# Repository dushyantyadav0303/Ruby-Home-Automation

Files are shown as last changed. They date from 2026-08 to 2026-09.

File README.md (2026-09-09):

<h1 align="center">
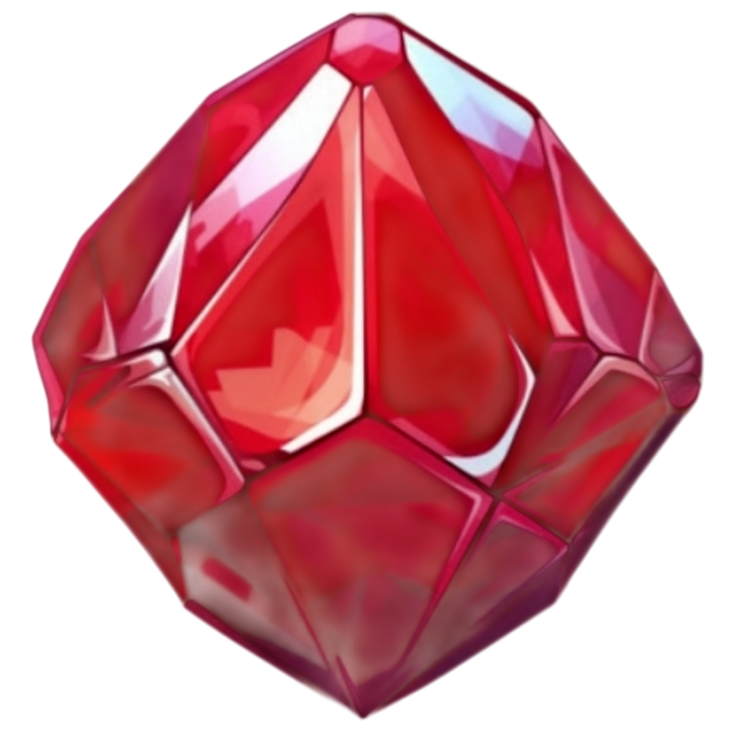
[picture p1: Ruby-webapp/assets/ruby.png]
banner
<br> 
</h1>
<div align="center">   
  

</div>

 <div align="center">   
  




</div>

<p align="center">
  <a href="#about-the-project">About</a> •
  <a href="#repository-structure">Structure</a> •
  <a href="#schematic">Schematic</a> •
  <a href="#pcb">PCB</a> •
  <a href="#cad">CAD</a> •
  <a href="#Render">Render</a> •
  <a href="#bill-of-materials">BOM</a> •
  <a href="#license">License</a> •
  <a href="#credits">Credits</a>
</p>  

https://github.com/user-attachments/assets/42d68add-5cff-4576-99cb-57eee04979b4

## Webapp: https://ruby-home-automation.vercel.app

### About the Project

**Ruby-Home-Automation** It is a aesthetic Home Automation Device With Multi color silkscreen, It connect with home Appliances and Make it control them using your phone From any corner of the world. And Also connect with Home assistant like Alexa & Google Assistant And control them using Voice command.
### Features

- **Wifi + ble**
- **Easy to configure with any firmware**
- **Controls 4 Lights, 1 fan With the 4 step Speed control, All the home appliances which uses IR Remote.**
- **IR receiver/IR Blaster**
- **Multicolor silkscreen**

## Repository Structure

- `src/PCB/` — EasyEDA project sources
- `src/cad/` — mechanical CAD sources
- `production/pcb/` — PCB fabrication files (Gerbers, BOM, Pick & Place)
- `production/cad/` — 3D-printing files (.stl + .3mf)
- `GETTING_STARTED/` — Setup guides, firmware installation, and board bring-up documentation
- `Journal/` — DevLogs With Timestamp
- `Firmware/` — Demo firmware

## Schematic

Source : `src/PCB/Sch`
## [Oshwlab](https://oshwlab.com/dushyant0303/project_avsrxfsp)
Schematic

## PCB 
Source : `src/PCB/Pcb`
~ 
<div align="center">

| Front PCB | Back PCB |
|---|---|
|  |  |
|  |  |

</div>

## CAD


A Encloser Case for Ruby home automation. The top part and bottom part are Friction fit , allowing the enclosure to be assembled without screws or Glue makes it easy assembly. And looks good.

- source: `src/cad/`
<div align="center">
<table>
<tr>
<td valign="bottom">
</td>
<td valign="bottom">
</table>
</div>
]

### 3D-printable Production files are available in:
- source: `production/cad/`

## Render 


<div align="center">
<table>
<tr>
<td valign="bottom">
</td>
<td valign="bottom">
</table>
</div>

## BOM

## Bill of Materials

Source: `BOM/BOM.csv`

|Quantity|Comment |Designator |Footprint |Price in USD|link |
|---|---|---|---|---|---|
|4 |0.1uf |C8,C1,C5,C7 |C0805 |$0.44 |https://www.lcsc.com/product-detail/C1711.html |
|1 |10nF |C2 |C0805 |$1.04 |https://www.lcsc.com/product-detail/C1710.html |
|1 |CH340C |U10 |SOP-16_L10.0-W3.9-P1.27-LS6.0-BL |$ 0.59 |https://www.lcsc.com/product-detail/C84681.html |
|1 |DHT11 |H1 |HDR-TH_4P-P2.54-V-M_146458-4 |$0.8 |https://robu.in/product/dht-11-digital-temperature-and-humidity-sensor-normal-quality |
|1 |ESP32-WROOM-32D |U12 |WIFIM-SMD_ESP32-WROOM-32D |$ 3.92 |https://www.lcsc.com/product-detail/C473012.html |
|1 |HT7833 |U11 |SOT-89_L4.5-W2.5-P1.50-LS4.2-BR |$ 0.61 |https://www.lcsc.com/product-detail/C3011187.html |
|1 |MX128-5.0-06P-GN01-Cu-Y-A|U13 |CONN-TH_6P-P5.00_MX128-5.0-06P-GN01-CU-Y-A|$ 0.36 |https://www.lcsc.com/product-detail/C5290371.html |
|1 |S6B-XH-A-GU |CN1 |CONN-TH_S6B-XH-A |$ 1.04 |https://www.lcsc.com/product-detail/C495565.html |
|1 |TSOP1738_TSOP1738 |U9 |TSOP1738:TSOP17XX |$ 0.43 |https://robocraze.com/products/tsop-1738 |
|1 |TYPE-C-31-M-12 |USBC1 |USB-C_SMD-TYPE-C-31-M-12_1 |$ 0.86 |https://www.lcsc.com/product-detail/C165948.html |
|1 |ULN2003LVDR |U1 |SOIC-16_L9.9-W3.9-P1.27-LS6.0-BL |$ 0.88 |https://www.lcsc.com/product-detail/C19723745.html |
|2 |2.2Ω |R22,R23 |RES-TH_BD2.2-L6.5-P10.50-D0.6 |$0.01 |https://kitsguru.com/products/2-2ω-resistance-1-4-watt-5-tolerance |
|2 |220kΩ |R14,R15 |RES-TH_BD4.5-L11.0-P15.00-D0.7 |$ 0.02 |https://robu.in/product/mf25-220k-multicomp-pro-through-hole-resistor-220-kohm-mf25-series-250-mw-±-1-axial-leaded-250-v/|
|2 |BC846B |Q5,Q6 |SOT-23-3_L2.9-W1.3-P1.90-LS2.4-BR |$ 0.76 |https://www.lcsc.com/product-detail/C181138.html |
|1 |2.2uf |C10 |CAP-TH_L12.0-W5.5-P10.00-D1.2 |$ 0.44 |https://www.lcsc.com/product-detail/Polypropylene-Film-Capacitors--CBB-_KNSCHA-MPP334J2G10AJ22610_C506821.html |
|1 |3.3uf |C9 |CAP-TH_L11.5-W6.3-P10.00-D0.6 |$ 0.44 |https://www.lcsc.com/product-detail/C22466724.html? |
|2 |TSA010A2518A |SW1,SW2 |SW-SMD_L4.0-W3.0-LS5.0 |$ 0.59 |https://www.lcsc.com/product-detail/C2888945.html |
|3 |5.1k |R8,R9,R19 |R0805_NEW |$ 1.13 |https://www.lcsc.com/product-detail/C27834.html |
|3 |10uF |C3,C4,C6 |C0805 |$ 0.52 |https://www.lcsc.com/product-detail/C27834.html |
|4 |10K |R7,R13,R20,R21 |R0805_NEW |$ 0.36 |https://www.lcsc.com/product-detail/C2907219.html |
|4 |LED |LED2,LED3,LED4,LED6 |LED0805-RD_RED_C0805YGC |$ 0.94 |https://www.lcsc.com/product-detail/C264434.html |
|6 |330Ω |R5,R6,R10,R11,R12,R25 |R0805_NEW |$ 0.56 |https://www.lcsc.com/product-detail/C19701189.html |
|7 |1k |R1,R2,R3,R4,R16,R17,R18 |R0805_NEW |$ 1.2 |https://www.lcsc.com/product-detail/C19699631.html |
|7 |1N4007W |D1,D2,D3,D4,D5,D6,D7 |SOD-123_L2.8-W1.8-LS3.7-RD |$ 0.72 |https://www.lcsc.com/product-detail/C2857183.html |
|7 |2N3904(SOT-23) |Q1,Q2,Q3,Q4,Q7,Q8,Q9 |SOT-23-3_L2.9-W1.3-P1.90-LS2.4-TR |$ 0.47 |https://www.lcsc.com/product-detail/C50176433.html |
|7 |IR333-A |U2,U3,U4,U5,U6,U7,U8 |LED-TH_BD6.2-P2.54-FD |$ 0.68 |https://www.lcsc.com/product-detail/C50176433.html |
|7 |SRD-05VDC-SL-C |RLY1,RLY2,RLY3,RLY4,RLY5,RLY6,RLY7|RELAY-TH_SRD-XXVDC-XL-C |$ 0.44 |https://www.lcsc.com/product-detail/C35449.html |
|1 |PCB | | |$14 |https://jlcpcb.com |
|Total | | | |$34.25 | |

> [!NOTE]
> Price As of August 25, 2026  <br/>
> & It not Include the Shipping fee

## License

Licensed under MIT — you can use this commercially, modify, and distribute 
with proper attribution. See [LICENSE](LICENSE) file.

## Contributing

Contributions, improvements, and remixes are welcome! Please read the [CONTRIBUTING.md](CONTRIBUTING.md) guide to get started.

## Credits
<div align="center">
  



 
</div>

This project was created during a [Hack Club](https://hackclub.com) event [Live YSWS](https://Live.hackclub.com).
- **[EasyEDA](https://easyeda.com)** - PCB design and schematic capture
- **[Fusion 360](https://www.autodesk.com/products/fusion-360)** - Cad Designing
- **[Blender](https://www.blender.org)** - Render
- **[@NotARoomba](https://github.com/notaroomba) & [@Gabouin](https://github.com/Gabouin)** - Readme template

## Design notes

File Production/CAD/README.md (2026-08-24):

# TOP

> [!IMPORTANT]
> This Should Be Printed in Transparent material like Clear Resin using SLA 3dp Technology.


----

| bottom | Led aliner |
| :---: | :---: |
|  |  |

| Specification | Default Value / Range |
| :--- | :--- |
| **Printer Nozzle** | 0.4 mm Stainless Steel | 
| **Layer Height** | 0.2 mm |
| **First Layer Height** | 0.2 mm |
| **Seam Position** | Random |
| **Nozzle Temperature** | Depends on your Filament |
| **Build Plate Temperature** | Depends on your Filament |
| **Sparse Infill Density** | 10% |
| **Max Toolhead Speed** | 500 mm/s |
| **Max Acceleration** | 10000 mm/s² |
| **Brim Width** | 3.5 mm |
| **Brim type** | Outer brim |

> [!NOTE] 
> Tested in Pla+ (Recommended)

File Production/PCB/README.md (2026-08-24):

| Ordering Detail | Cart |
| :---: | :---: |
| ordering-detail | cart |

~ Source [JLCPCB Docs](https://jlcpcb.com/help/article/how-to-design-multi-color-silkscreen-using-easyeda)
<details>
  <summary> Click to see "How to Design Multi-Color Silkscreen Using EasyEDA"</summary>

## Table of Contents
1. [Introduction](#introduction)
2. [Enabling Color Silkscreen Printing](#enabling-color-silkscreen-printing)
3. [Importing Color Images](#importing-color-images)
4. [Setting Component Silkscreen Colors](#setting-component-silkscreen-colors)
5. [Setting Board Silkscreen Colors](#setting-board-silkscreen-colors)
6. [Previewing Color Silkscreen](#previewing-color-silkscreen)
7. [Exporting Manufacturing Files](#exporting-manufacturing-files)
8. [Ordering Multi-Color Circuit Board](#ordering-multi-color-circuit-board)
9. [Important Notes for Multi-Color Silkscreen PCBs](#important-notes-for-multi-color-silkscreen-pcbs)

---

## Introduction

JLCPCB is one of the few PCB manufacturers capable of offering multi-color silkscreen services. To produce a multi-color circuit board, a design incorporating multi-color silkscreens is essential. At present, our production process exclusively supports Gerber files featuring colored silkscreen layers that have been exported from **EasyEDA Pro**. 

In the following guide, we will walk you through the process of designing multi-color silkscreens using EasyEDA Pro, including importing color images, setting character colors, and exporting manufacturing files for orders through JLCPCB.

---

## Enabling Color Silkscreen Printing

To begin, activate the "Use JLCPCB Color Silkscreen Process" option in the PCB settings:
* **Path:** Settings icon – PCB / Footprint – General – Using JLC color silkscreen technology

---

## Importing Color Images

1. EasyEDA supports importing color images via the **Top Menu – Place – Image**. 
2. Both **PNG** and **SVG** vector image files are supported. 
3. In the import dialog, tick the option to place the image in original quality. If this option is not available, try uploading the image in another file format.
4. The image will automatically be placed on the top silkscreen layer, but you can move it to the document layer or the bottom silkscreen layer if needed.

---

## Setting Component Silkscreen Colors

* After selecting a component, you can set its silkscreen color in the **right-side properties panel**.
* All lines, text, reference designators, and other silkscreen features belonging to the component will be printed in this color.

---

## Setting Board Silkscreen Colors

Click on a blank space on the canvas to access the color silkscreen settings in the right-side properties panel:
* **Top/Side Board Colors:** Default is white. Since the board requires color printing, a base color layer must be printed first, and this setting determines that base color.
* **Top/Bottom Side Silkscreen Colors:** The default silkscreen colors, like reference designators and component outline silkscreens. If a component has an individually set silkscreen color, it will take precedence over this default.

---

## Previewing Color Silkscreen

1. Go to **Top Menu – View – 2D/3D Preview**.
2. You must set **Silkscreen Technology** to **Colorful Silkscreen** in the right-side properties panel to see the effect of color printing.

---

## Exporting Manufacturing Files

1. After completing the settings and editing the color silkscreen, export the color silkscreen production file. 
2. Open **Top Menu – Export – PCB Fabrication File (Gerber)**.
3. Tick the **Silkscreen** option to export color silkscreen along with the Gerber files.

### Important SMT / Panelization Notes:
* **Edge Rails Requirement:** If your color silkscreen board requires JLCPCB SMT service, ensure that the "Panelize" function has been set with edge rails. Otherwise, the color silkscreen will not be printed when you select SMT service.
* Click "Set Technology Side", or access the Panelize menu from **Top Menu – Tools – Panelize**. Choose the panelization method ("Stamp Hole" / "V-CUT"), then enable process edges ("Create Technology Side"). The panel format can be 1×1 or larger.
* **EasyEDA Pro Version Support:** In EasyEDA Pro version 2.2 and above, color silkscreen panelization is supported when selecting **"All Objects"** as the panelization method within the Panelize tool. Currently, the "Board Outline Only" panelization method does not support color silkscreen.
* **Single-Layer Boards Caution:** Please exercise caution when designing single-layer boards with color silkscreen. If your single-layer routing is placed on the bottom layer, JLCPCB will mirror the bottom layer data to the top layer during manufacturing to optimize production efficiency and reduce costs. However, the color silkscreen data will not be mirrored synchronously, resulting in the color silkscreen being mistakenly printed over top layer pads. **Recommendation:** Place all routing on the top layer when designing single-layer boards, or design the project as a double-layer board by applying a copper pour to the unrouted layer.

---

## Ordering Multi-Color Circuit Board

You can place an order directly at EasyEDA, or upload Gerber files generated from EasyEDA on the JLCPCB quote page, where you need to select multi-color silkscreen specifications.

### Multi-Color Silkscreen PCB Specifications:

| Specification | Supported Option |
| :--- | :--- |
| **Layers** | 2 layers, 4 layers |
| **PCB Color** | White |
| **Outer Copper Weight** | 1oz |
| **Surface Finish** | ENIG |
| **Gold Thickness** | 1u |
| **Via Covering** | Tented, Untented, Plugged |
| **Delivery Format** | Single PCB, Panel by Customer |

* In the **"Advanced Options"**, select **"EasyEDA multi-color silkscreen"** under Silkscreen Technology.

---

## Important Notes for Multi-Color Silkscreen PCBs

1. **Gerber Adjustments Error Tolerance:** EasyEDA color silkscreen production files are separate from Gerber. JLCPCB adjusts customer's Gerber files to ensure compatibility with process conditions, but these adjustments do not carry over to color silkscreen files. If Gerber adjustments exceed the set error tolerance of **2 mm**, your color silkscreen will not be included in the production files.
2. **Panel Size for V-Cut:** Please ensure that the PCB panel size is **≥ 70×70 mm** if there is a V-Cut. For sizes smaller than this, please panel with mouse bites.
3. **Edge Rails for SMT Assembly:** When the size is less than 70×70 mm, the system will automatically add edge rails to enlarge the size, and engineers will align the multi-color silkscreen on the board. Edge rails are added with V-Cut for regular shapes and mouse bites for irregular shapes.
4. **EasyEDA Pro Panelize Limitation:** Currently, multi-color silkscreen is not fully supported by EasyEDA Pro's automatic Panelize feature, as automatic panelization does not duplicate multi-color silkscreen content. The exported multi-color silkscreen Gerber will only have data on the master board, and other boards will not contain multi-color silkscreen files.

</details>

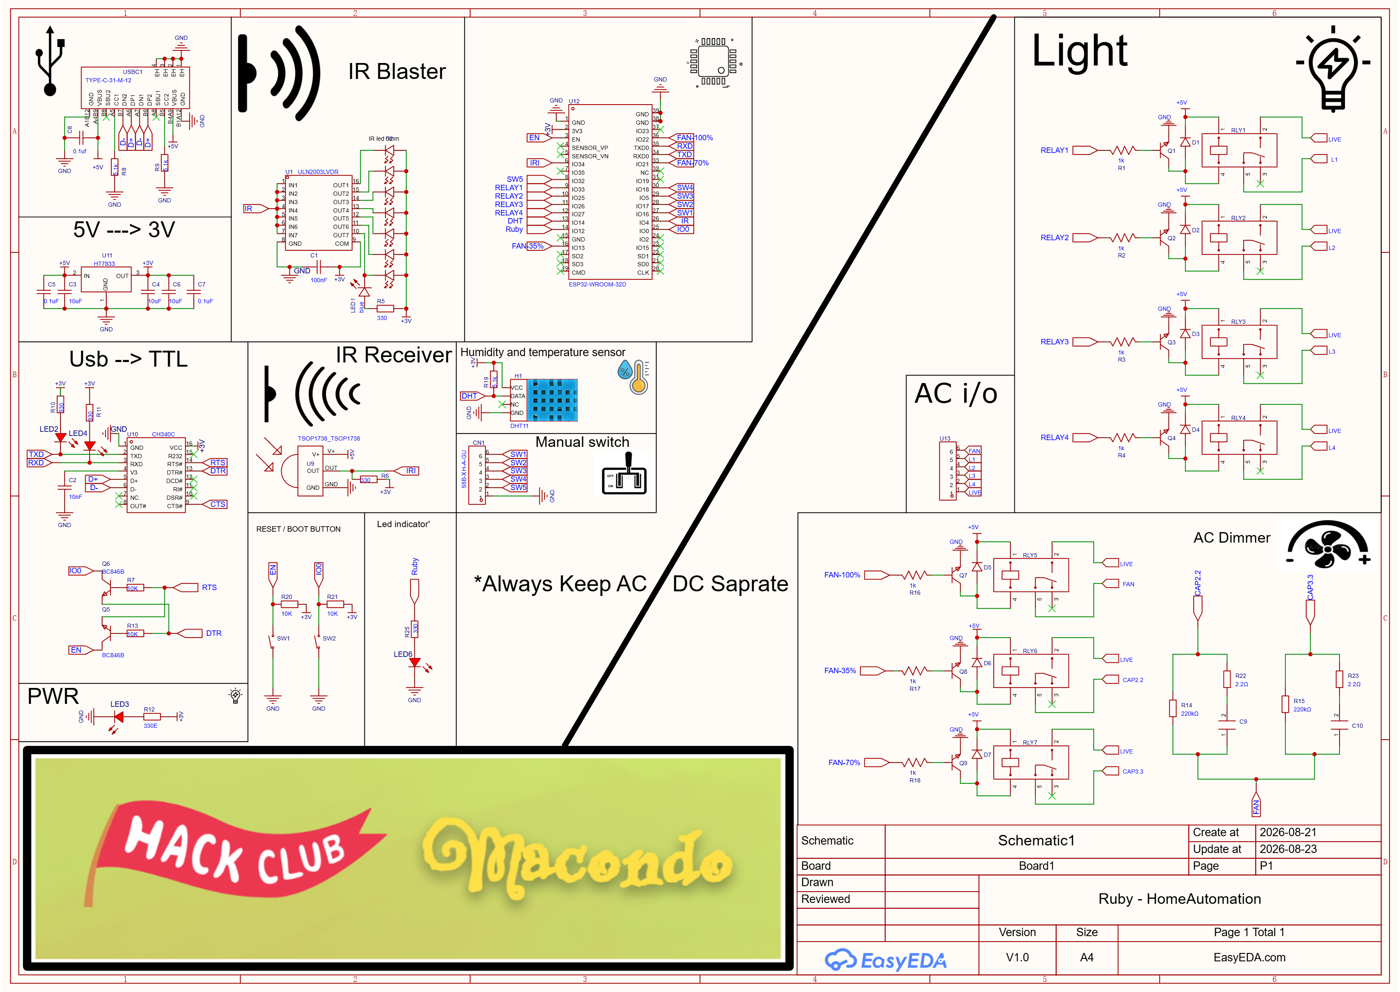
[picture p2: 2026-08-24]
src/PCB/Schematic.png

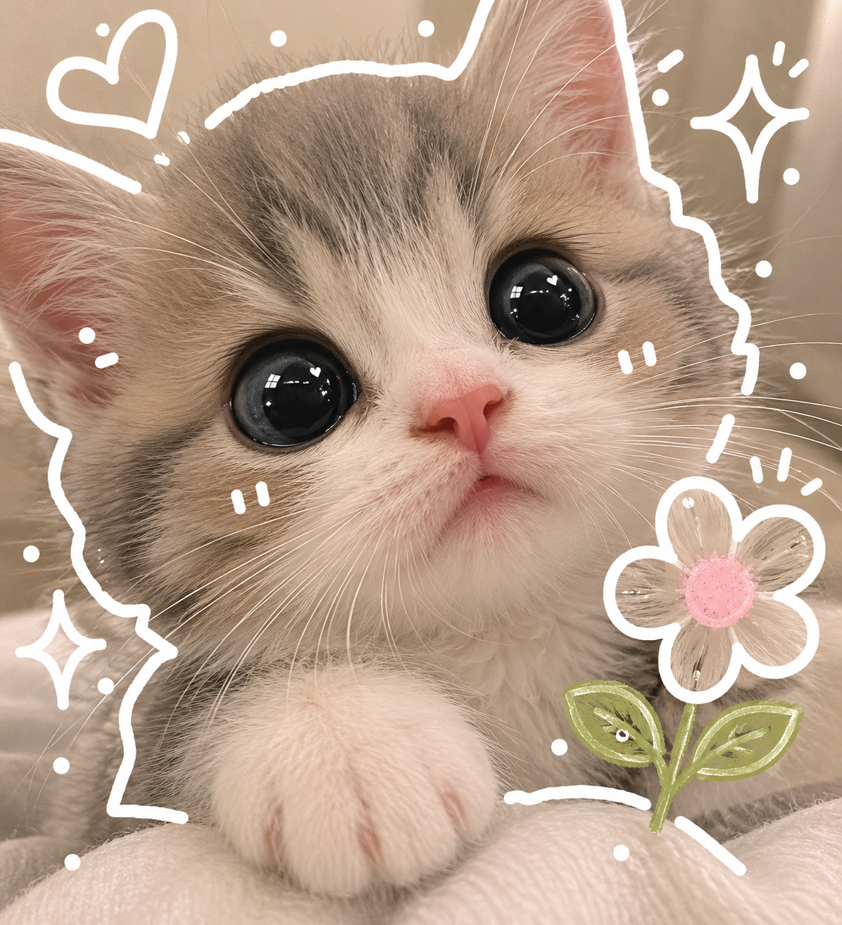
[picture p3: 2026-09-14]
Ruby-webapp/assets/photo.png

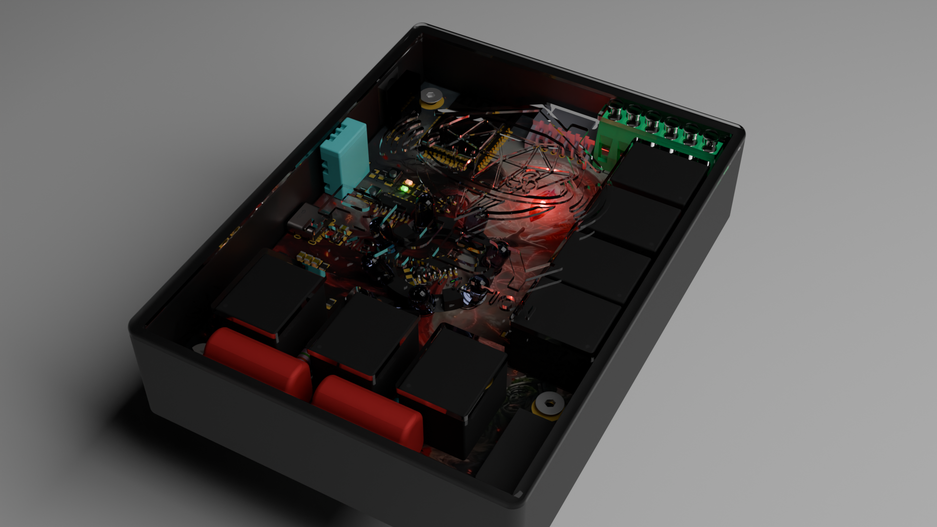
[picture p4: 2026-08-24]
Render/Render.png

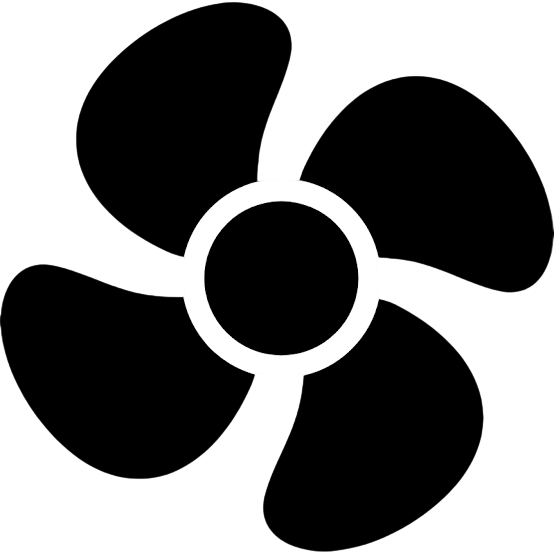
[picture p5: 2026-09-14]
Ruby-webapp/assets/fan.png

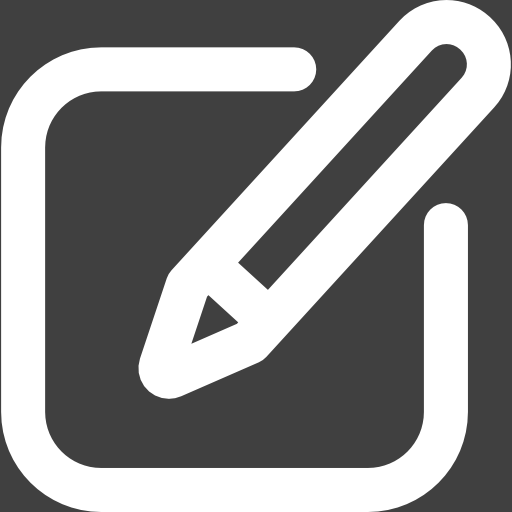
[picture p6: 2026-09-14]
Ruby-webapp/assets/edit.png

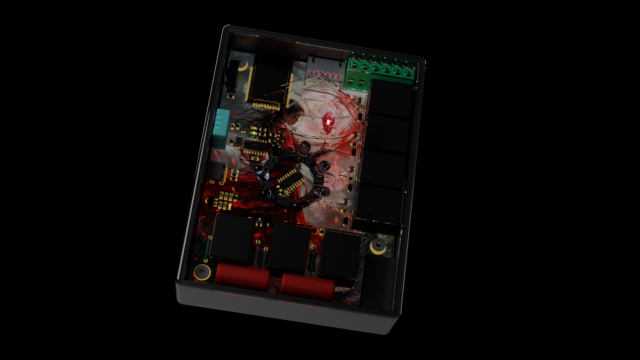
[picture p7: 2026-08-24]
Render/Render2.png

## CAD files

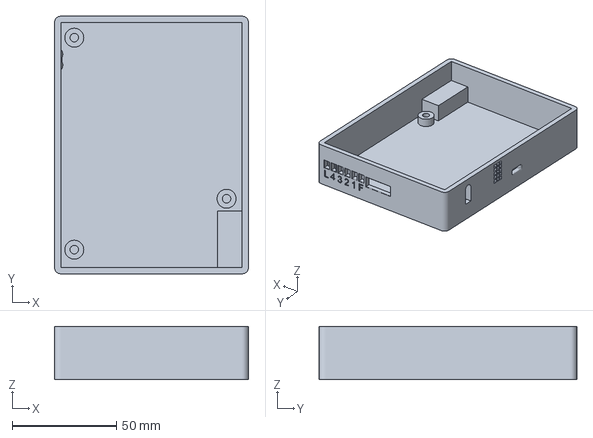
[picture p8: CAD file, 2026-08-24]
Production/CAD/BOTTOM.3mf
93.0 x 123.5 x 25.5 mm

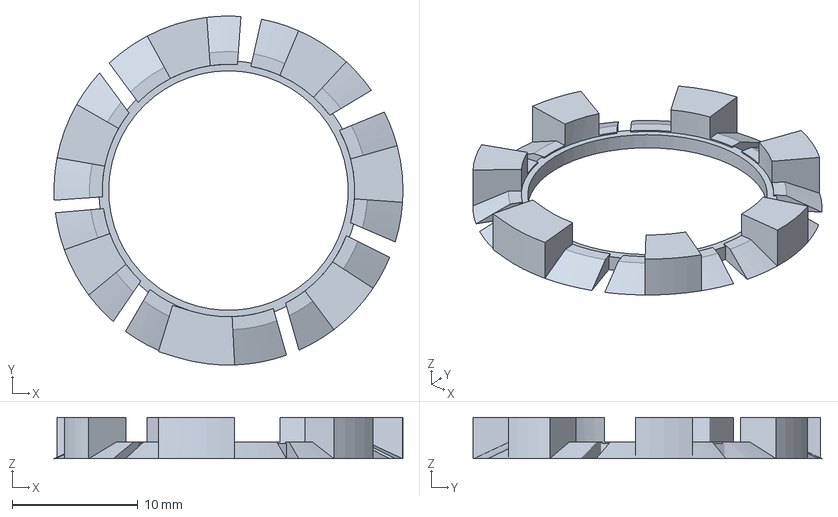
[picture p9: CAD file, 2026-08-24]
Production/CAD/IR led holder.3mf
27.8 x 27.8 x 3.30 mm

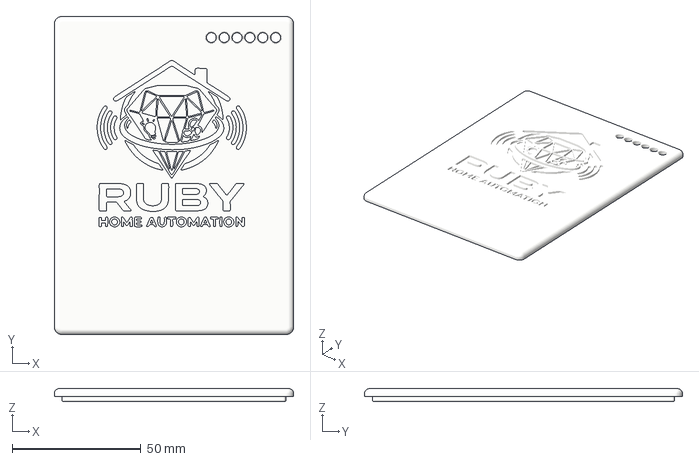
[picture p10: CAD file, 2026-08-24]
Production/CAD/TOP.3mf
93.0 x 123.5 x 5.00 mm

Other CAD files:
Production/CAD/stl file/BOTTOM.stl
Production/CAD/stl file/IR led holder.stl
Production/CAD/stl file/TOP.stl
Render/ruby.blend

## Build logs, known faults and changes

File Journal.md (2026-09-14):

>  [!NOTE]
>  Time logged: 30hr Journal +  59.2Lapse/hackatime  = 89.2hr <br/>
> Please don't do deflation Most of the thing are lapses and 0% AI code and Really awesome project

<table>
  <tr>
    <td></td>
    <td></td>
  </tr>
</table>

## https://hackatime.hackclub.com/@dushyantYadav0303/project/Ruby-webapp
## https://hackatime.hackclub.com/@dushyantYadav0303/project/ruby 

## title: "Ruby Home Automation"
## description: 
"**Ruby-Home-Automation** It is a aesthetic Home Automation Device With Multi color silkscreen, It connect with home Appliances and Make it control them using your phone From any corner of the world. And Also connect with Home assistant like Alexa & Google Assistant And control them using Voice command.

### Features

- **Wifi + ble**
- **Easy to configure with any firmware**
- **Controls 4 Lights, 1 fan With the 4 step Speed control, All the home appliances which uses IR Remote.**
- **IR receiver/IR Blaster**
- **Multicolor silkscreen**"
---

---
---

# September 14th:  completed the [webapp](https://ruby-home-automation.vercel.app)
## yoo gng,
### I finally completed the Web here you see the demo 
https://github.com/user-attachments/assets/afb32e5a-3740-4272-8d85-8ec8a7474dab

---

# August 31st: working on data base
ahhhh today i am Working on data base and hackatim eis going on <br/>here you see the plan
<br/> 
so there is 2 database: for device Data and Authorization <br/>
And I really want to thank Firebase Guide it's very helpful. vvv

---

# August 28th: working on website
## lapse: <br/>working on website!!!!
<br/>lock in!<br/>
<br/>it is very sick webapp yooooo!!!!
<br/>still working on it!!!!!!<br/>


---

# August 27th: Order Completed!
<br/>
# PCB + PCBA
<br/>
# 3dp
## Ahh Rejected logo Without any official Document is not allowed.
### So sadly I have to remove it
<br/>
# After removing the logo It get approved!!!
& then I paying the payment<br/><br/>

---

# August 26th: placing order
## Lapse: https://lapse.hackclub.com/timelapse/cg--xQHDWiDK
# Hello
## Today, I'm ordering the PCB + PCBA and the And encloser for ruby Home Automation from [JLCPCB](https://jlcpcb.com) and [JLC3DP](https://jlc3dp.com)
### First I Selected the best setting for PCB and PCBA
## Here you see what I set V

## Now most of the time is taken by Setting the best component of best price. in the PCBA. And after working a lot. I finally Selected this component. 
### Also i uncheck few Components like relay, DHT11 sensor & Connector Which are really very expensive.

## Next I verify all the component placement. To ensure everything is Properly aligned.

# next 3D printed Encloser from [JLC3DP](https://jlc3dp.com)
## So the main thing is that the encloser should be fully transparent And for that we need to choose the correct setting And technology of printing.
### So I select This setting to achieve the transparent print Possible .

## After that I selected the shipping method. And research little bit about Tariff and And such all things
### Now I submitted the order for review Once it is approved I can make the payment. 

---

# August 25th: BOM + Component fix
## Lapse: https://lapse.hackclub.com/timelapse/WiXx7qWq5Ogr
# hello
## today I work on BOM part and fixes
## Yo so I started with Matching the criteria According to macondo docs.
### According to it I needed the price and link to buy Which is not there in bom
### So I start adding Links one by one But this time I'm Adding the [lcsc](https://www.lcsc.com) link cause Many users not belong to India. and at India store there isn't Enough information & Data sheet.
### While adding the link I figure out some issues in the PCB
The footprint I use Through hole capacitor is not Easily Available. also the capacitor height is also More than the Encloser. Which is not the issue to ignore.
## So lot of research I find the correct Through hole capacitor Which exactly fit in And closer.
## Then I continue adding the link. If the component is not available on [lcsc](https://www.lcsc.com) or it is Expensive I added the third party link. 
## At last I converted everything in markdown and added to reamde too. 

---

# August 23rd: REPO!!!!!
## lapse: https://lapse.hackclub.com/timelapse/FThonnutK1Yl
## only 8 min left in Mocondo end ahhhh
## In very hurry so here's a quick Recap what I did
## I export all the file necessary And given in the docs. 
## added Buying guide in the production folder so It is very easy for Beginner to reproduce it.
## Overall I have a good time with the Macondo.
## Thank you so much , happy review
## Also I forward to tell that I make the read me 
## not ai genrated JSAJSJASJJAS


---

# August 22nd: Firmware
## lapse: https://lapse.hackclub.com/timelapse/issSMHaDB7yv
# helo
## I'm cooked there is very less time in event ends and my project still needs time.
## So make the more then enougf code for my project. still i want to work more on it. no worry I will do this before build ship.
## also i tested the server related part and it works fine.
## here is the code i write 
<br/>

---

# August 21st: Render/animation
## lapse: https://lapse.hackclub.com/timelapse/7l4N7iDAVsMz
# hola gng!
## today, i am working on making the render of the ruby home automation,
## so i started with the importing the 3d model, in .fbx format for better Quality.
## Next I work on adding textures. For all the components cause It really matter!!!. it also The default Textures added on the component is very bad. Might be because it is not design for blender. 
## then I added the lightings which is also matter alot. Good lighting is a Secret of good render. Even Idk why I am ryming tho.
## next, I click some render
### here you see 
<br/>
## Then I start working on the animation So my plan is to 
- make it Rotate 360<br/>- Open the enclosure<br/>- camera goes closer to component <br/>- And after showing the Ruby fading effect It goes back and encloser closes<br/>hmmm It might be change in a while
## Yo so I finally complete the render.
## Here you see the timeline in setup 

### wait 8 hour For rendering it

## you not have to wait here you see 
video

---

# August 19th: Finalize Case
## lapse: https://lapse.hackclub.com/timelapse/_EffqP0L-rQ9
# hello 
## So as we know Yesterday I Make some changes in the PCB and Finalize it. Now today is the Case turn.
## So what the changes I made:
- First I Import the new model and Re adjust the heat inserts According to the new PCB.<br/>- next, The easyeda don't direcly exports the Multicolor silkscreen so i have to Manually added it.<br/>- then i Add just newly added dht-11 sensor and added the Air vents <br/>- then i works on polishing it. like Adjusting the relay groves, Re orienting the logo and Some finishing touch.
### After all here's the final model:
<br/>

---

# August 18th: Finalize PCB
## lapses - https://lapse.hackclub.com/timelapse/SymVh-PORV4T 
### yooo 8.5hr lapse!!!
# Helololo
## today, I am giving the final Touch to my PCB in which 
- Fixing the issues<br/>- Adding more things<br/>- Polish the routing<br/>- Adding multicolor silkscreen<br/>- much more!!!!<br/><br/>
## yoo, So there's a lot of things which I fix. I will tell the major things I did
### So I saw some issues in the systematic which I fix:
<br/>- fixes the ac dimmer for fan.<br/>- Added the boot and reset button<br/>- Then I Added the Ruby led to glow up the Ruby Stone.<br/>- Instead of connecting dht-11 module I added dht-11 Sensor directly on the board.<br/>- little bit Polish the systematic. <br/>- Here you see Final systematic.<br/><br/>
## Next I work on the PCB where Majorly I work on optimising it
how ? <br/>- So I optimise the routing. <br/>- Component placement <br/>- Adjusting the Width of routes According to their power. <br/>- ask in channel For Suggestion to improve it <br/>- added all the Footprints and a 3D models<br/><br/><br/>
## Then I remove all the unwanted Comments on slik screen and added the multicolor silkscreen. Which look incredible.
### are you ready ??
## here you gooooooo


---

# August 17th: fixing Case
## Lapse: https://lapse.hackclub.com/timelapse/2Ib48VLwxcP6
# Hola!
## Today, I'm working on the fixing CAD model.
## First i added this IR led holder which help to Aline the led in all directions. 
### Here how it's look
<br/>
# wait Did you realise if I added the Case on top of it how Ir light passes ???
## So I have few solution
- add holes on the cad {Which not looks good}<br/>- make a Transparent case {looks sick}
### Soo Yea as you all know What I'm going to select Transparent case 
## Now how to make transparent case ??
- Translucent FDM printed CASE {not allow ir light to pass properly}<br/>- use Acrylic sheet {good idea it's cheap but not too good}.<br/>- use SLA printed case with clear resin 
### sla printing idea comes from Nathan ember project.

## So yeaaa I'm going with Sla printing option even it is little bit expensive tho.
### next i remove the snap fit connect cause it is diffcult sla print (resin it more rigid)
## first i added the screw to connect but it look soo ugly 
### Then i think how to fit it now, so then i ask in #hardware huddle and they Recommend me to use friction fit. With tight tolerance.

## And really it is a very good idea. So modify it according and also polish the model.
## here is the final result.


---

# August 13th: Simulation fail !
# ah-LOH, Today I'm making Simulation for Snap fit joint cause i made that joint by own
### Starting with zero I don't have any past experience with simulation in Fusion360, I just heard about it in videos.
### first I looking for some tutorials and Any startup guide but There is no much resources available expect via fusion 360. So I decided to learn By myself only or you saw Make experiment with them, 
### After watching some short Startup guild I start creating the simulation. 
### Started with removing the object Which is not required, Assign the material { in which pla is Not there so I select the abs plastic And change their density to 1.25 }, then Make the part consistent , Apply force of the Moving over. Then I run the DOF view 

### Then run the simulation it take ~30 min approx For one Simulation 
### And it get failed I tried to fix the issue Searching for the solution, And 4 simulation study and all are fail, 
Now I'm over for today, I will do it tomorrow Might be tomorrow it works.
### **Total time spent: 2.7h**

---

# August 11th: Making Case #3
# Hola!, Today i Going to work on top part of the Case.
## so what i did
###  Make snap fit Mechanism which is very strong AFAIK better then out Previous one
<br/>
# also i added Graphics on the top of the lid which looks very GOOD
<br/>
### **Total time spent: 1.9h**

---

# August 10th: Making Case #2
# Today, I'm Start Designing Case For Ruby Home AUtomation 
## Started with Bottom part 
- I'm Maintaining the tolerance of 1mm between PCB and Case.<br/>- Also Making most of the edges curve.
### here is Bottom Part 
<br/><br/>
### **Total time spent: 1h**

---

# August 10th: Making Case #1
# Today! I Start building The Case For the Ruby-HomeAutomation
## First I ADDed 3 Hole in PCB of 3mm

## then I Build the PCB Locking or clampping Mechanism.
- This Time i think Something Unique Previously I use This mechanism VV <br/>
## I make a New Locking mechanism which have 4 Hook to Hold the PCB 
<br/>
### It take more time cause I am Not see this type of locking Mechanism before.
### **Total time spent: 1.4h**

---

# August 9th: Add texture
# Today, I added the Proper texture According to there Material and Characteristic.
- Start with ESP32 in which I added Polished Steel for Top Sheald <br/>- For IR Led and Receiver I add the Tinted Glass texture after many Trial<br/>- then for all the Remaining,
## NOTE- It might Be not see Change In First look but When I make a Render in Blender You See the Change Clear.
### after all here the result
<br/>
### **Total time spent: 0.8h**

---

# August 8th: PCB Render
# Today!, I am Making a Render of PCB in Blender. I love doing this + this time I using 4 light Blend.
### Here is the Blender
<br/><br/><br/>
# Setup

### **Total time spent: 1.6h**

---

# August 6th: Posted On oshwlab
After asking On #macondo-help For "Does i use oshwlab for Demo link" and they Allow me then I post all the file and detail over there.
# [LINK](https://oshwlab.com/dushyant0303/project_avsrxfsp)

### **Total time spent: 1h**

---

# August 5th: Finalize PCB
# Today i give the Finishing touch to the PCB
### I Arrange the IR LED In a proper circle 

### Added All the remaining 3D model
- Relay<br/>- IR receiver<br/>- etc.<br/>
### **Total time spent: 1h**

---

# August 4th: Silkscreen
# Today, I'm adding the Silkscreen on the PCB 
## My plan is To add the band like Logo on PCB 
- ex-<br/>
## here how it look
<br/>
### **Total time spent: 1.2h**

---

# August 4th: Copper Pour
# Today I work on the Copper pour
### Top layer copper pour net i use GND

### Bottom layer copper pour A split into 2 part 
- +3v3<br/>- +5v
###The copper pour is very far from Live wires 

### **Total time spent: 0.5h**

---

# August 2nd: Optimize size + Route PCB
There are lot of missing space More to watch, So I rearrange all the components To make it more optimize Still if you see there is a lot of space left but I'm Using it cause of the EMF radiation It affects the signal quality and create noise<br/><br/>
### **Total time spent: 1.8h**

---

# August 1st: Routing the PCB
Finally I again come to my best part Routing the PCB This time I managed EMF And separate the live line And Dc Line. Almost half work is completed today Now I'm moving forward Tomorrow <br/>
### **Total time spent: 1.6h**

---

# August 1st: layouting the PCB
So today I am layouting the PCB And this time I have to be very careful cause There is two power lines 240v live and 3v3 for Board. So I have to make it separate Otherwise It interrupt each other signal.<br/>And I have Maintain proper safety With the Live wire, And the live have Small arear as possible.
## Here is the final Layout!

### **Total time spent: 1.8h**

---

# July 31st: Making new component
I Didn't find the footprint And the component for "2.2µF 225J 250V CBB22 Metallized Polypropylene Film Capacitor" <br/>So I build my own component Starting with 
### Symbol
<br/>Looks like a regular Capacitor
### Footprint
After conducting a researcher & Scrolling some data sheet I made this <br/><br/>After combining All Of them Here is the final result <br/>
### **Total time spent: 1.2h**

---

# July 30th: Completed fan regulator
So Instead of Going with that digital Fan regulator, I go with the tradition for regulator which Still use in most of the home Without any issue,
## Here is the circuit diagram

### **Total time spent: 1h**

---

# July 29th: Working on systematic
So today I added More features in My home automation system<br/>1. Add Temperature and humidity sensor {DHT11}<br/><br/>2. Add manual Switches<br/><br/>3. Working on Fan regulator<br/>
### **Total time spent: 1h**

---

# July 28th: Streamline Systematic
Yesterday i complete the systematic But is very Difficult to understand cause the components are not arrange properly and the no commment or headline<br/><br/>so today I work to fixing it & here is the final result<br/><br/>Still I'm working on controlling the Fan Speed Once it is completed we are good to go to PCB Designing
### **Total time spent: 1h**

---

# July 26th: Working on systematic
Today I Adding the IR Receiver & MCU With Auto Programming Circuit Togather Make Easy to use "just plug and Play" No need to use a external TTL converter.
## IR Receiver 

## MCU- ESP32-WROOM-32D-N4 With Programmer
<br/>Now we Almost Completed the Systematic Only the part left is the fan control It is easy to turn on &of the Fan But I don't know how to control their speed. Let's see this Part tomorrow
### **Total time spent: 1.5h**

---

# July 26th: Preparing systematic
First of all I am changing my decision I'm going with Sugar Cube relay Cause of high Current Holding Capacity .<br/>- First I add 4 Relays For Light Control <br/><br/>- IR Blaster - I use ULN2003LVDR instead of Transistors which help to Saves Space and Handle power and Signal better acc. to Some Sources<br/>
### **Total time spent: 1.1h**

---

# July 25th: Hardware selection
So let's start with MCU selection -<br/><br/>So the features I want in the MCU It control Relay, It Support wifi compatibility & Have enough GPIO Pins. In my case of ESP32 is the best option <br/><br/><br/>Relay selection - <br/><br/>Most commonly used relay is <br/>- sugar cube relay - It have 2x Size 2x Power handling capacity 2x Energy consumption<br/><br/><br/>- Small relay- it have less Size less Power handling capacity less Energy consumption<br/><br/><br/>Comparison Due to sugar cube relay Have a high power Consumption and Huge Size we rejecting it. <br/>And selecting a small relay.<br/><br/>For IR Blaster - We are using IR LED & TSOP1738 IR Receiver<br/>And overall it required High current We will add External 12 volt power socket
### **Total time spent: 1.2h**

---

# July 23rd: Planning Feature
# Planning Feature
## About my project 
Ruby - An home automation system Which is Used to Control Home Appliance like Lights, Fan, Air conditioners, Etc.<br/>- which Can be Integrated with Alexa, Google Home & Home-Assistant<br/>- Also controlled Via Ir/Rf Remote & Manual Switches (Works Offine)<br/>- Relay and Ir blaster to control Home Appliance <br/>For now I am planning to control 4 lights, 1 Fan, 20+ IR devices ex- Television & Air conditioners
### For Presentation I Prepare a Chart on Figma 

### **Total time spent: 1.4h**

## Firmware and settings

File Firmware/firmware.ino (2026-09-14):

// This is demo firmware for ruby home automtion project
// It might have bugs. but will fix it once I received the hardware
// Also I will integrate the Home assistant, Rainmaker, kme soon!
// Thank you so much for understanding.!
// I check the realtime server connectvity and other thing runing on stand alone esp32

// Credits
// This project mostly used the example code given for esp32 
// thanks to https://randomnerdtutorials.com for fire base guide

#define ENABLE_USER_AUTH
#define ENABLE_DATABASE


#include <Arduino.h>
#include <WiFi.h>
#include <WiFiClientSecure.h>
#include <FirebaseClient.h>
#include "DHT.h"
#include <IRremoteESP8266.h>
#include <IRrecv.h>
#include <IRsend.h>
#include <IRutils.h>


// lights controls
#define relay1 33
#define relay2 25
#define relay3 26
#define relay4 27

// Fan control
#define relay5 13
#define relay6 21
#define relay7 22

// SW Input
#define SW1 16
#define SW2 17
#define SW3 5
#define SW4 18
#define SW5 32

// indicator
#define Ruby 12

// IR reciver
#define IRI 34

// IR Blaster
#define IR 4

IRrecv irrecv(IRI);
IRsend irsend(IR);
decode_results results;

uint32_t savedIRCodes[4] = {0, 0, 0, 0};
int lastUsedSwitch = 1;

int brightness = 0;
int fadeAmount = 5;
unsigned long lastFadeTime = 0;


#define BOOT_BTN 0

#define DHT_PIN 14
#define DHTTYPE DHT11
DHT dht(DHT_PIN, DHTTYPE);


const char *ssid = "LAPTOP 4429";
const char *password = "5}042Gx9";
const char *DATABASE_URL = "https://ruby-homeautomation-default-rtdb.firebaseio.com";
unsigned long lastSensorSendTime = 0;
const unsigned long sensorInterval = 10000;

void processData(AsyncResult &aResult);

NoAuth no_auth;
FirebaseApp app;
WiFiClientSecure ssl_client;
using AsyncClient = AsyncClientClass;
AsyncClient aClient(ssl_client);
RealtimeDatabase Database;


// The value after bootup
int lastSW1 = LOW, lastSW2 = LOW, lastSW3 = LOW, lastSW4 = LOW;
int currentFanSpeed = 0;
int lastFanSpeed = -1;

// Variables to send to the database
int intValue = 0;
String stringValue = "";


void setup(){
pinMode (relay1, OUTPUT);
pinMode (relay2, OUTPUT);
pinMode (relay3, OUTPUT);
pinMode (relay4, OUTPUT);
pinMode (relay5, OUTPUT);
pinMode (relay6, OUTPUT);
pinMode (relay7, OUTPUT);
pinMode (Ruby, OUTPUT);
pinMode (IR, OUTPUT);
pinMode (SW1, INPUT_PULLUP);
pinMode (SW2, INPUT_PULLUP);
pinMode (SW3, INPUT_PULLUP);
pinMode (SW4, INPUT_PULLUP);
pinMode(DHT_PIN, INPUT);
pinMode (IRI, INPUT);

Serial.begin(115200);
dht.begin();

WiFi.begin(ssid, password);
  Serial.print("Connecting to WiFi");
  while (WiFi.status() != WL_CONNECTED) {
    delay(500);
    Serial.print(".");
  }
  Serial.println("");
  Serial.println("WiFi connected!");
  Serial.print("IP address: ");
  Serial.println(WiFi.localIP());



  ssl_client.setInsecure();
  ssl_client.setConnectionTimeout(1000);
  ssl_client.setHandshakeTimeout(5);
  


 initializeApp(aClient, app, getAuth(no_auth), processData, "authTask");
  app.getApp<RealtimeDatabase>(Database);
  Database.url(DATABASE_URL);

pinMode(BOOT_BTN, INPUT_PULLUP);
irrecv.enableIRIn();
irsend.begin();

}

void loop(){
  app.loop();



if (digitalRead(SW1) == LOW){
  digitalWrite(relay1, HIGH);
  if (app.ready()) Database.set<int>(aClient, "/Appliances/relay1", 1, processData, "Set_Relay1");
  } else {
    digitalWrite(relay1, LOW);
  }

if (digitalRead(SW2) == LOW){
  digitalWrite(relay2, HIGH);
  if (app.ready()) Database.set<int>(aClient, "/Appliances/relay2", 1, processData, "Set_Relay2");
   } else {
  digitalWrite(relay2, LOW);
   }

if (digitalRead(SW3) == LOW){
  digitalWrite(relay3, HIGH);
   } else {
    digitalWrite(relay3, LOW);
if (app.ready()) Database.set<int>(aClient, "/Appliances/relay3", 0, processData, "Set_Relay3");
   }

if (digitalRead(SW4) == LOW){
  digitalWrite(relay4, HIGH);
if (app.ready()) Database.set<int>(aClient, "/Appliances/relay4", 1, processData, "Set_Relay4");
   } else {
    digitalWrite(relay4, LOW);
   }






int SW_value = analogRead(SW5);
int detectedSpeed = 0;

if (SW_value > 3500) {
  digitalWrite(relay5, LOW);
  digitalWrite(relay6, LOW);
  digitalWrite(relay7, LOW);
  detectedSpeed = 0;
} else if (SW_value > 2500) {
  digitalWrite(relay5, HIGH);
  digitalWrite(relay6, LOW);
  digitalWrite(relay7, LOW);
  detectedSpeed = 1;
   } else if (SW_value > 1500) {
  digitalWrite(relay5, LOW);
  digitalWrite(relay6, HIGH);
  digitalWrite(relay7, LOW);
  detectedSpeed = 2;
 } else {
  digitalWrite(relay5, LOW);
  digitalWrite(relay6, LOW);
  digitalWrite(relay7, HIGH);
  detectedSpeed = 3;
 }

if (detectedSpeed != lastFanSpeed) {
    lastFanSpeed = detectedSpeed;
    if (app.ready()) Database.set<int>(aClient, "/Appliances/fan", detectedSpeed, processData, "Set_Fan");
  }


if (app.ready()) {
    unsigned long currentTime = millis();
    if (currentTime - lastSensorSendTime >= sensorInterval) {
      lastSensorSendTime = currentTime;

      float h = dht.readHumidity();
      float t = dht.readTemperature();
if (!isnan(h) && !isnan(t)) {
        Database.set<float>(aClient, "/sensor/temperature", t, processData, "RTDB_Temp");
        Database.set<float>(aClient, "/sensor/humidity", h, processData, "RTDB_Humid");

if (digitalRead(BOOT_BTN) == LOW) {
  analogWrite(Ruby, 255);
  unsigned long startWait = millis();
  bool captured = false;
  while (millis() - startWait < 5000) {
    if (irrecv.decode(&results)) {
      if (results.value != 0 && results.value != 0xFFFFFFFF) {
        savedIRCodes[lastUsedSwitch - 1] = results.value;
        captured = true;
        irrecv.resume();
        break;
      }
      irrecv.resume();
    }
    delay(10);
  }
  if (captured) blinkRuby(4);
  else analogWrite(Ruby, 0);
         }


if (irrecv.decode(&results)) {
  uint32_t code = results.value;
  if (code != 0 && code != 0xFFFFFFFF) {
    for (int i = 0; i < 4; i++) {
      if (savedIRCodes[i] != 0 && code == savedIRCodes[i]) {
        int targetRelay = (i == 0) ? relay1 : (i == 1) ? relay2 : (i == 2) ? relay3 : relay4;
        int newState = !digitalRead(targetRelay);
        digitalWrite(targetRelay, newState);
        blinkRuby(1);
        if (app.ready()) Database.set<int>(aClient, ("/Appliances/relay" + String(i + 1)).c_str(), newState, processData, "IR_Set");
        break;
      }
    }
  }


  irrecv.resume();
}


      }
    }
  }
}

void processData(AsyncResult &aResult) {
 if (aResult.isError()) {
    Firebase.printf("Error task: %s, msg: %s, code: %d\n", aResult.uid().c_str(), aResult.error().message().c_str(), aResult.error().code());
  }

  if (aResult.available()) {
    Firebase.printf("Task completed: %s\n", aResult.uid().c_str());
  }
}


void handleRubyBreathing() {
  unsigned long currentMillis = millis();
  if (currentMillis - lastFadeTime >= 20) {
    lastFadeTime = currentMillis;
    analogWrite(Ruby, brightness);
    brightness += fadeAmount;
    if (brightness <= 0 || brightness >= 255) fadeAmount = -fadeAmount;
  }
}

void blinkRuby(int times) {
  for (int i = 0; i < times; i++) {
    analogWrite(Ruby, 255); delay(100);
    analogWrite(Ruby, 0); delay(100);
  }
}



/*
It is Your Duty to begin creating your own Amazing Project using the ruby While Taking Firmware as Reference,
And explore & learn more about the board's capabilities.
 Happy hacking!
If you're experiencing an issue that is not covered in this guide, please open a GitHub Issue.
*/

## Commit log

2026-08-24 added production
    [BOTTOM.3mf, BOTTOM.stl, IR led holder.3mf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]
2026-08-24 added pcb
    [BOM.csv, PickAndPlace.csv]
2026-08-24 added Blender src
    [ruby.blend]
2026-08-24 Enhance README with multi-color silkscreen details
    Updated README.md to include detailed instructions for enabling and using multi-color silkscreen printing with EasyEDA and JLCPCB, along with a table of contents and important notes.
2026-08-24 Create README.md for CAD production guidelines
    Added detailed specifications and printing instructions for CAD production.
2026-08-24 ADDED BOM
    [BOM.csv]
2026-09-13 Change the device status from dummy to real db
    Configure Real time Firebase database with Device status so it shows the Realtime device status
2026-09-14 change the device data from dummy to real
2026-09-14 added a Device key generation For link Device with webapp
2026-09-14 completed the Home page with lights and fan controlls
2026-09-14 Revise BOM with updated components and prices
    Updated BOM.csv to reflect new components and pricing.
    [BOM.csv]
2026-09-14 Add initial firmware for Ruby home automation
    Initial commit of demo firmware for Ruby home automation project, including WiFi connectivity, relay control, and sensor data handling.

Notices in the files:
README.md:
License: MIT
